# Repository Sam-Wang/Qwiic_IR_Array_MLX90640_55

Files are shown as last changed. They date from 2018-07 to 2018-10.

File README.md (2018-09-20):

Qwiic IR Array (MLX90640-55x35 FOV)
==================

Qwiic IR Array

[*Qwiic IR Array (SEN-14844)*](https://www.sparkfun.com/products/14844)

The MLX90640 contains a 32x24 array of thermopile sensors creating, in essence, a low resolution thermal imaging camera.

Repository Contents
-------------------
* **/Documentation** - Datasheets. 
* **/Firmware** - Examples to use the MLX90640 with a microcontroller.
* **/Hardware** - All Eagle design files (.brd, .sch). 
* **/Production** - Various test jigs and large panel layouts used for production.

Documentation
--------------
* **[Library](https://github.com/sparkfun/SparkFun_MLX90640_Arduino_Example)** - Arduino library for the Qwiic IR Array.
* **[Hookup Guide](https://learn.sparkfun.com/tutorials/qwiic-ir-array-mlx90640-hookup-guide)** - Basic hookup guide for the Qwiic IR Array.

Product Versions
----------------
* [SEN-14844](https://www.sparkfun.com/products/14844)- SparkFun red version
* [SPX-14769](https://www.sparkfun.com/products/14769)- SparkX version

License Information
-------------------

The hardware is released under [Creative Commons ShareAlike 4.0 International](https://creativecommons.org/licenses/by-sa/4.0/).
The code is beerware; if you see me (or any other SparkFun employee) at the local, and you've found our code helpful, please buy us a round!

Distributed as-is; no warranty is given.

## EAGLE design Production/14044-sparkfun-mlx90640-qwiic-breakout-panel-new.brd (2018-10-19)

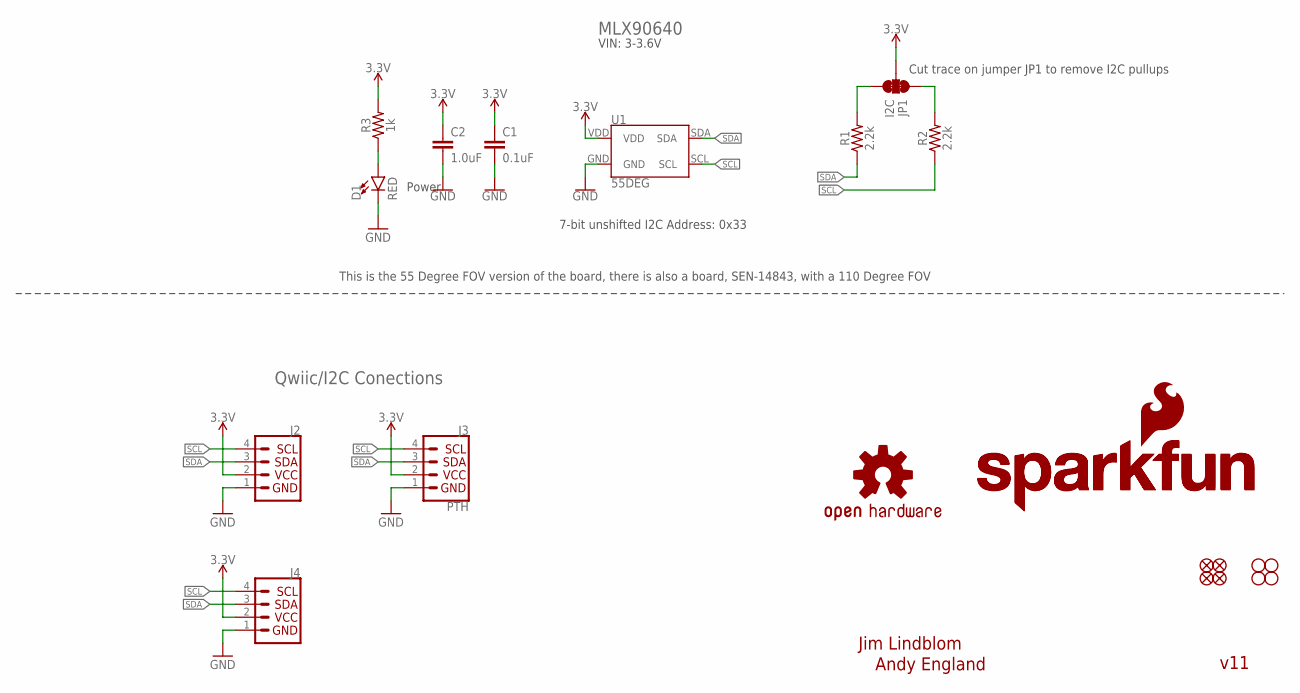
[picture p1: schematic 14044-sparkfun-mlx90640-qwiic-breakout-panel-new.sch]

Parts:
C1: 0.1uF; 0603
C2: 1.0uF; 0603
D1: RED; LED-0603
J2, J4: QWIIC_CONNECTORJS-1MM; 1X04_1MM_RA
J3: PTH; 1X04_NO_SILK
JP1: I2C; SMT-JUMPER_3_2-NC_TRACE_NO-SILK
JP2, JP5, JP6, JP7: FIDUCIALUFIDUCIAL; MICRO-FIDUCIAL
JP3, JP4, JP8, JP9: STAND-OFF
LOGO1: OSHW-LOGOMINI; OSHW-LOGO-MINI
LOGO2: SFE_LOGO_NAME_FLAME.1_INCH; SFE_LOGO_NAME_FLAME_.1
LOGO3: SFE_LOGO_NAME.1_INCH; SFE_LOGO_NAME_.1
R1, R2: 2.2k; 0603
R3: 1k; 0603
U1: 55DEG; MLX90540_MLX90640

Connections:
3.3V: C1.1, C2.1, J2.2, J3.2 (VCC), J4.2, JP1.2, R3.2, U1.VDD
GND: C1.2, C2.2, D1.C, J2.1, J3.1 (GND), J4.1, U1.GND
unnamed: JP1.3, R1.2
unnamed: JP1.1, R2.2
unnamed: D1.A, R3.1
SCL: J2.4, J3.4 (SCL), J4.4, R2.1, U1.SCL
SDA: J2.3, J3.3 (SDA), J4.3, R1.1, U1.SDA

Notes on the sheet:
Power
Jim Lindblom
7-bit unshifted I2C Address: 0x33
v11
Andy England
MLX90640
Qwiic/I2C Conections
VIN: 3-3.6V
This is the 55 Degree FOV version of the board, there is also a board, SEN-14843, with a 110 Degree FOV
Cut trace on jumper JP1 to remove I2C pullups

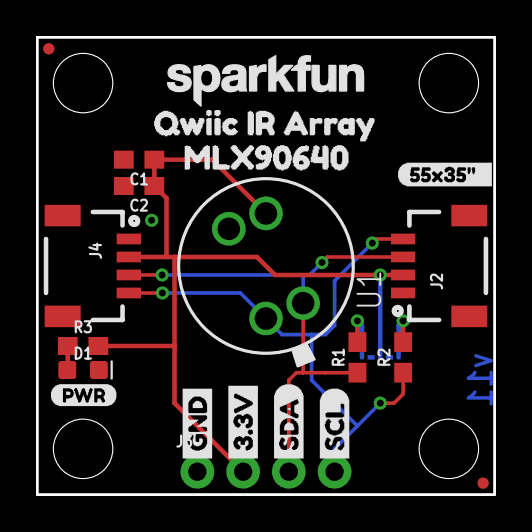
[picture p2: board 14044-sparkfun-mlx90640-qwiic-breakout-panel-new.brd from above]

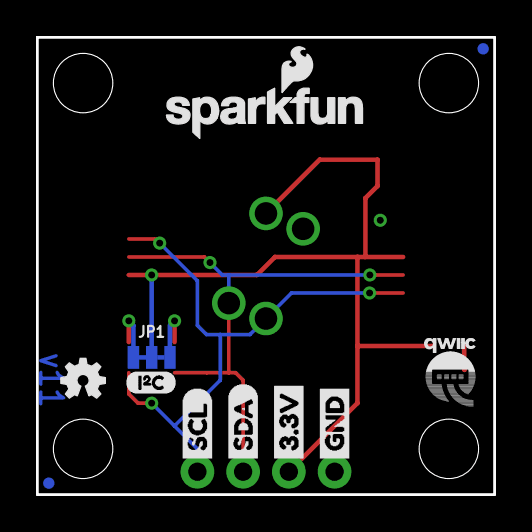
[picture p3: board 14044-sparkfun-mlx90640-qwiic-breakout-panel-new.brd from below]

Board: 2 copper layers, 25.4 x 25.4 mm, 36 parts (11 on the bottom side), 7 nets.

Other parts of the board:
U$1, U$7: SDA-[)
U$2: 55X35#__0
U$4, U$8: SCL-[)
U$5, U$9: 3.3V
U$6, U$10: GND-04
U$11: QWIIC-LOGO-SMALL
U$12: PWR-()-03
U$13: MLX906401
U$14: QWIIC_IR_ARRAY0
U$16: I_SUPER2_C-()-03

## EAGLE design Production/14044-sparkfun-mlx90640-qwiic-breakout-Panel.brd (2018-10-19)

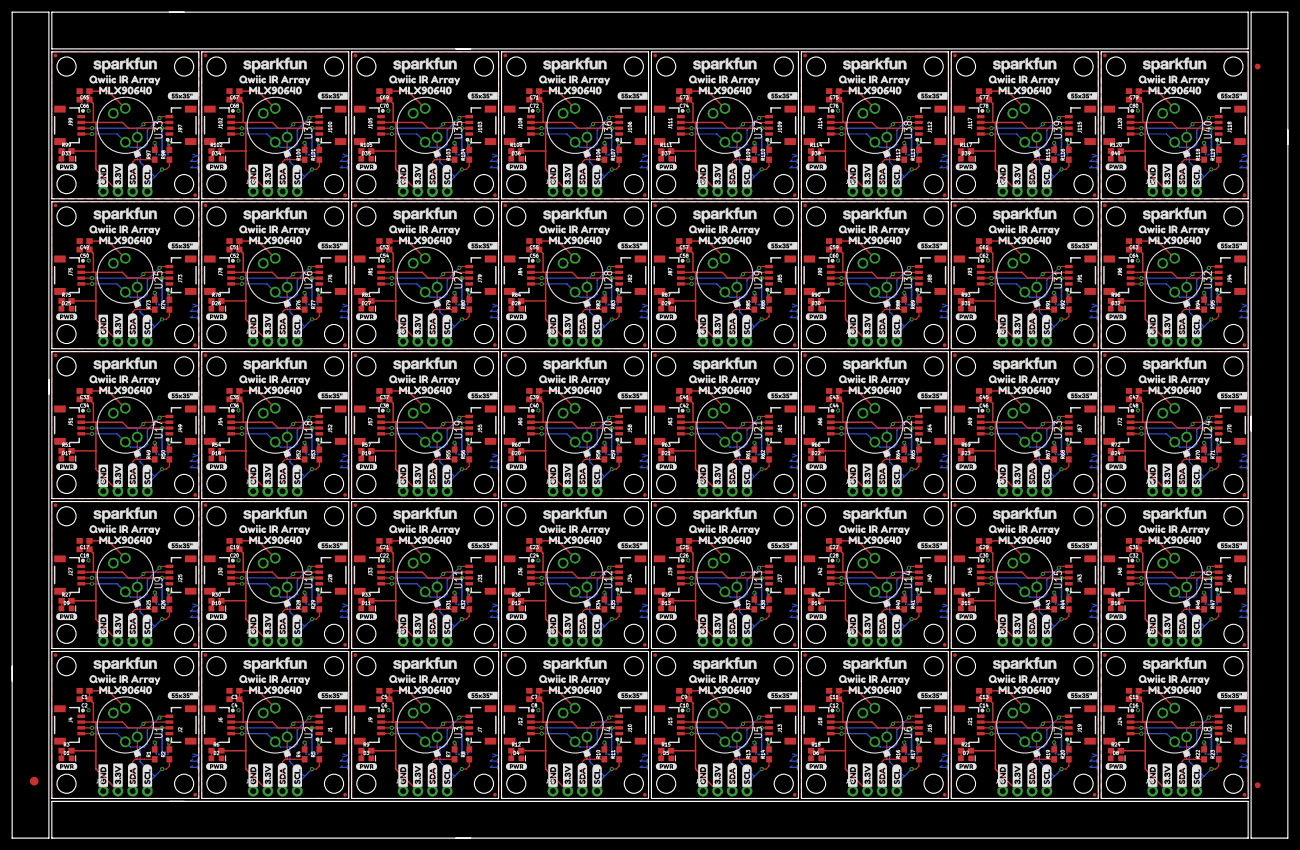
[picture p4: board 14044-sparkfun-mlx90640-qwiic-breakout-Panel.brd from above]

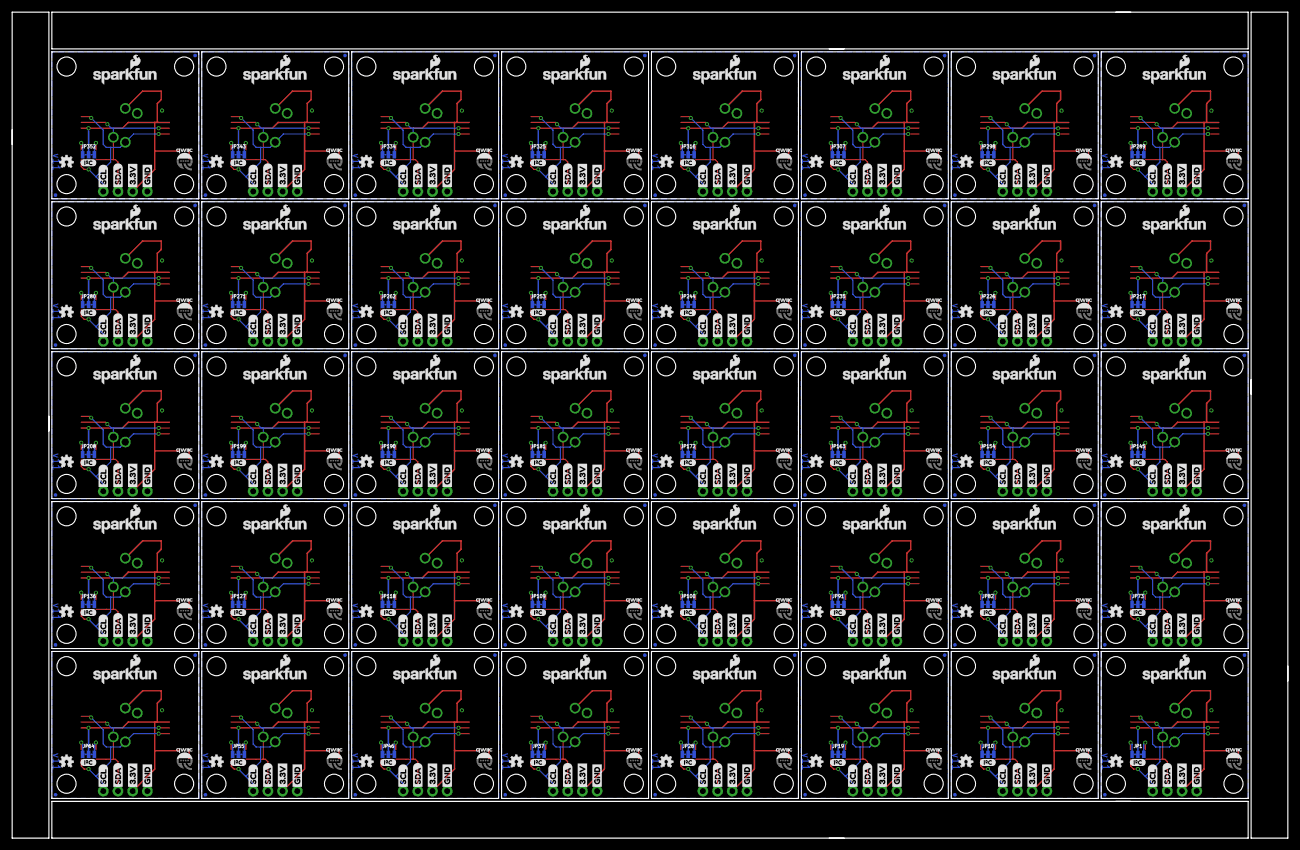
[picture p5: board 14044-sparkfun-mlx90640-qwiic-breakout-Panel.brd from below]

Board: 2 copper layers, 220.5 x 142.7 mm, 1443 parts (440 on the bottom side), 280 nets.

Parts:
C1, C3, C5, C7, C9, C11, C13, C15, C17, C19, C21, C23, C25, C27, C29, C31, C33, C35, C37, C39, C41, C43, C45, C47, C49, C51, C53, C55, C57, C59, C61, C63, C65, C67, C69, C71, C73, C75, C77, C79: 0.1uF; 0603
C2, C4, C6, C8, C10, C12, C14, C16, C18, C20, C22, C24, C26, C28, C30, C32, C34, C36, C38, C40, C42, C44, C46, C48, C50, C52, C54, C56, C58, C60, C62, C64, C66, C68, C70, C72, C74, C76, C78, C80: 1.0uF; 0603
D1, D2, D3, D4, D5, D6, D7, D8, D9, D10, D11, D12, D13, D14, D15, D16, D17, D18, D19, D20, D21, D22, D23, D24, D25, D26, D27, D28, D29, D30, D31, D32, D33, D34, D35, D36, D37, D38, D39, D40: RED; LED-0603
E$3: FIDUCIAL-1.5X3
E$7, E$8: FIDUCIAL-1X2
J1, J2, J4, J6, J7, J9, J10, J12, J13, J15, J16, J18, J19, J21, J22, J24, J25, J27, J28, J30, J31, J33, J34, J36, J37, J39, J40, J42, J43, J45, J46, J48, J49, J51, J52, J54, J55, J57, J58, J60, J61, J63, J64, J66, J67, J69, J70, J72, J73, J75, J76, J78, J79, J81, J82, J84, J85, J87, J88, J90, J91, J93, J94, J96, J97, J99, J100, J102, J103, J105, J106, J108, J109, J111, J112, J114, J115, J117, J118, J120: 1X04_1MM_RA
J3, J5, J8, J11, J14, J17, J20, J23, J26, J29, J32, J35, J38, J41, J44, J47, J50, J53, J56, J59, J62, J65, J68, J71, J74, J77, J80, J83, J86, J89, J92, J95, J98, J101, J104, J107, J110, J113, J116, J119: PTH; 1X04_NO_SILK
JP1, JP10, JP19, JP28, JP37, JP46, JP55, JP64, JP73, JP82, JP91, JP100, JP109, JP118, JP127, JP136, JP145, JP154, JP163, JP172, JP181, JP190, JP199, JP208, JP217, JP226, JP235, JP244, JP253, JP262, JP271, JP280, JP289, JP298, JP307, JP316, JP325, JP334, JP343, JP352: I2C; SMT-JUMPER_3_2-NC_TRACE_NO-SILK
JP2, JP5, JP6, JP7, JP13, JP14, JP15, JP16, JP22, JP23, JP24, JP25, JP31, JP32, JP33, JP34, JP40, JP41, JP42, JP43, JP49, JP50, JP51, JP52, JP58, JP59, JP60, JP61, JP67, JP68, JP69, JP70, JP76, JP77, JP78, JP79, JP85, JP86, JP87, JP88, JP94, JP95, JP96, JP97, JP103, JP104, JP105, JP106, JP112, JP113, JP114, JP115, JP121, JP122, JP123, JP124, JP130, JP131, JP132, JP133, JP139, JP140, JP141, JP142, JP148, JP149, JP150, JP151, JP157, JP158, JP159, JP160, JP166, JP167, JP168, JP169, JP175, JP176, JP177, JP178, JP184, JP185, JP186, JP187, JP193, JP194, JP195, JP196, JP202, JP203, JP204, JP205, JP211, JP212, JP213, JP214, JP220, JP221, JP222, JP223, JP229, JP230, JP231, JP232, JP238, JP239, JP240, JP241, JP247, JP248, JP249, JP250, JP256, JP257, JP258, JP259, JP265, JP266, JP267, JP268, JP274, JP275, JP276, JP277, JP283, JP284, JP285, JP286, JP292, JP293, JP294, JP295, JP301, JP302, JP303, JP304, JP310, JP311, JP312, JP313, JP319, JP320, JP321, JP322, JP328, JP329, JP330, JP331, JP337, JP338, JP339, JP340, JP346, JP347, JP348, JP349, JP355, JP356, JP357, JP358: FIDUCIALUFIDUCIAL; MICRO-FIDUCIAL
JP3, JP4, JP8, JP9, JP11, JP12, JP17, JP18, JP20, JP21, JP26, JP27, JP29, JP30, JP35, JP36, JP38, JP39, JP44, JP45, JP47, JP48, JP53, JP54, JP56, JP57, JP62, JP63, JP65, JP66, JP71, JP72, JP74, JP75, JP80, JP81, JP83, JP84, JP89, JP90, JP92, JP93, JP98, JP99, JP101, JP102, JP107, JP108, JP110, JP111, JP116, JP117, JP119, JP120, JP125, JP126, JP128, JP129, JP134, JP135, JP137, JP138, JP143, JP144, JP146, JP147, JP152, JP153, JP155, JP156, JP161, JP162, JP164, JP165, JP170, JP171, JP173, JP174, JP179, JP180, JP182, JP183, JP188, JP189, JP191, JP192, JP197, JP198, JP200, JP201, JP206, JP207, JP209, JP210, JP215, JP216, JP218, JP219, JP224, JP225, JP227, JP228, JP233, JP234, JP236, JP237, JP242, JP243, JP245, JP246, JP251, JP252, JP254, JP255, JP260, JP261, JP263, JP264, JP269, JP270, JP272, JP273, JP278, JP279, JP281, JP282, JP287, JP288, JP290, JP291, JP296, JP297, JP299, JP300, JP305, JP306, JP308, JP309, JP314, JP315, JP317, JP318, JP323, JP324, JP326, JP327, JP332, JP333, JP335, JP336, JP341, JP342, JP344, JP345, JP350, JP351, JP353, JP354, JP359, JP360: STAND-OFF
LOGO1, LOGO4, LOGO7, LOGO10, LOGO13, LOGO16, LOGO19, LOGO22, LOGO25, LOGO28, LOGO31, LOGO34, LOGO37, LOGO40, LOGO43, LOGO46, LOGO49, LOGO52, LOGO55, LOGO58, LOGO61, LOGO64, LOGO67, LOGO70, LOGO73, LOGO76, LOGO79, LOGO82, LOGO85, LOGO88, LOGO91, LOGO94, LOGO97, LOGO100, LOGO103, LOGO106, LOGO109, LOGO112, LOGO115, LOGO118: OSHW-LOGOMINI; OSHW-LOGO-MINI
LOGO2, LOGO5, LOGO8, LOGO11, LOGO14, LOGO17, LOGO20, LOGO23, LOGO26, LOGO29, LOGO32, LOGO35, LOGO38, LOGO41, LOGO44, LOGO47, LOGO50, LOGO53, LOGO56, LOGO59, LOGO62, LOGO65, LOGO68, LOGO71, LOGO74, LOGO77, LOGO80, LOGO83, LOGO86, LOGO89, LOGO92, LOGO95, LOGO98, LOGO101, LOGO104, LOGO107, LOGO110, LOGO113, LOGO116, LOGO119: SFE_LOGO_NAME_FLAME.1_INCH; SFE_LOGO_NAME_FLAME_.1
LOGO3, LOGO6, LOGO9, LOGO12, LOGO15, LOGO18, LOGO21, LOGO24, LOGO27, LOGO30, LOGO33, LOGO36, LOGO39, LOGO42, LOGO45, LOGO48, LOGO51, LOGO54, LOGO57, LOGO60, LOGO63, LOGO66, LOGO69, LOGO72, LOGO75, LOGO78, LOGO81, LOGO84, LOGO87, LOGO90, LOGO93, LOGO96, LOGO99, LOGO102, LOGO105, LOGO108, LOGO111, LOGO114, LOGO117, LOGO120: SFE_LOGO_NAME.1_INCH; SFE_LOGO_NAME_.1
R1, R2, R4, R5, R7, R8, R10, R11, R13, R14, R16, R17, R19, R20, R22, R23, R25, R26, R28, R29, R31, R32, R34, R35, R37, R38, R40, R41, R43, R44, R46, R47, R49, R50, R52, R53, R55, R56, R58, R59, R61, R62, R64, R65, R67, R68, R70, R71, R73, R74, R76, R77, R79, R80, R82, R83, R85, R86, R88, R89, R91, R92, R94, R95, R97, R98, R100, R101, R103, R104, R106, R107, R109, R110, R112, R113, R115, R116, R118, R119: 2.2k; 0603
R3, R6, R9, R12, R15, R18, R21, R24, R27, R30, R33, R36, R39, R42, R45, R48, R51, R54, R57, R60, R63, R66, R69, R72, R75, R78, R81, R84, R87, R90, R93, R96, R99, R102, R105, R108, R111, R114, R117, R120: 1k; 0603
U1, U2, U3, U4, U5, U6, U7, U8, U9, U10, U11, U12, U13, U14, U15, U16, U17, U18, U19, U20, U21, U22, U23, U24, U25, U26, U27, U28, U29, U30, U31, U32, U33, U34, U35, U36, U37, U38, U39, U40: 55DEG; MLX90540_MLX90640
U$1, U$3, U$7, U$19, U$29, U$33, U$43, U$47, U$57, U$61, U$71, U$75, U$85, U$89, U$99, U$103, U$113, U$117, U$127, U$131, U$141, U$145, U$155, U$159, U$169, U$173, U$183, U$187, U$197, U$201, U$211, U$215, U$225, U$229, U$239, U$243, U$253, U$257, U$267, U$271, U$281, U$285, U$295, U$299, U$309, U$313, U$323, U$327, U$337, U$341, U$351, U$355, U$365, U$369, U$379, U$383, U$393, U$397, U$407, U$411, U$421, U$425, U$435, U$439, U$449, U$453, U$463, U$467, U$477, U$481, U$491, U$495, U$505, U$509, U$519, U$523, U$533, U$537, U$547, U$551: SDA-[)
U$2, U$28, U$42, U$56, U$70, U$84, U$98, U$112, U$126, U$140, U$154, U$168, U$182, U$196, U$210, U$224, U$238, U$252, U$266, U$280, U$294, U$308, U$322, U$336, U$350, U$364, U$378, U$392, U$406, U$420, U$434, U$448, U$462, U$476, U$490, U$504, U$518, U$532, U$546, U$560: 55X35#__0
U$4, U$8, U$15, U$20, U$30, U$34, U$44, U$48, U$58, U$62, U$72, U$76, U$86, U$90, U$100, U$104, U$114, U$118, U$128, U$132, U$142, U$146, U$156, U$160, U$170, U$174, U$184, U$188, U$198, U$202, U$212, U$216, U$226, U$230, U$240, U$244, U$254, U$258, U$268, U$272, U$282, U$286, U$296, U$300, U$310, U$314, U$324, U$328, U$338, U$342, U$352, U$356, U$366, U$370, U$380, U$384, U$394, U$398, U$408, U$412, U$422, U$426, U$436, U$440, U$450, U$454, U$464, U$468, U$478, U$482, U$492, U$496, U$506, U$510, U$520, U$524, U$534, U$538, U$548, U$552: SCL-[)
U$5, U$9, U$17, U$21, U$31, U$35, U$45, U$49, U$59, U$63, U$73, U$77, U$87, U$91, U$101, U$105, U$115, U$119, U$129, U$133, U$143, U$147, U$157, U$161, U$171, U$175, U$185, U$189, U$199, U$203, U$213, U$217, U$227, U$231, U$241, U$245, U$255, U$259, U$269, U$273, U$283, U$287, U$297, U$301, U$311, U$315, U$325, U$329, U$339, U$343, U$353, U$357, U$367, U$371, U$381, U$385, U$395, U$399, U$409, U$413, U$423, U$427, U$437, U$441, U$451, U$455, U$465, U$469, U$479, U$483, U$493, U$497, U$507, U$511, U$521, U$525, U$535, U$539, U$549, U$553: 3.3V
U$6, U$10, U$18, U$22, U$32, U$36, U$46, U$50, U$60, U$64, U$74, U$78, U$88, U$92, U$102, U$106, U$116, U$120, U$130, U$134, U$144, U$148, U$158, U$162, U$172, U$176, U$186, U$190, U$200, U$204, U$214, U$218, U$228, U$232, U$242, U$246, U$256, U$260, U$270, U$274, U$284, U$288, U$298, U$302, U$312, U$316, U$326, U$330, U$340, U$344, U$354, U$358, U$368, U$372, U$382, U$386, U$396, U$400, U$410, U$414, U$424, U$428, U$438, U$442, U$452, U$456, U$466, U$470, U$480, U$484, U$494, U$498, U$508, U$512, U$522, U$526, U$536, U$540, U$550, U$554: GND-04
U$11, U$23, U$37, U$51, U$65, U$79, U$93, U$107, U$121, U$135, U$149, U$163, U$177, U$191, U$205, U$219, U$233, U$247, U$261, U$275, U$289, U$303, U$317, U$331, U$345, U$359, U$373, U$387, U$401, U$415, U$429, U$443, U$457, U$471, U$485, U$499, U$513, U$527, U$541, U$555: QWIIC-LOGO-SMALL
U$12, U$24, U$38, U$52, U$66, U$80, U$94, U$108, U$122, U$136, U$150, U$164, U$178, U$192, U$206, U$220, U$234, U$248, U$262, U$276, U$290, U$304, U$318, U$332, U$346, U$360, U$374, U$388, U$402, U$416, U$430, U$444, U$458, U$472, U$486, U$500, U$514, U$528, U$542, U$556: PWR-()-03
U$13, U$25, U$39, U$53, U$67, U$81, U$95, U$109, U$123, U$137, U$151, U$165, U$179, U$193, U$207, U$221, U$235, U$249, U$263, U$277, U$291, U$305, U$319, U$333, U$347, U$361, U$375, U$389, U$403, U$417, U$431, U$445, U$459, U$473, U$487, U$501, U$515, U$529, U$543, U$557: MLX906401
U$14, U$26, U$40, U$54, U$68, U$82, U$96, U$110, U$124, U$138, U$152, U$166, U$180, U$194, U$208, U$222, U$236, U$250, U$264, U$278, U$292, U$306, U$320, U$334, U$348, U$362, U$376, U$390, U$404, U$418, U$432, U$446, U$460, U$474, U$488, U$502, U$516, U$530, U$544, U$558: QWIIC_IR_ARRAY0
U$16, U$27, U$41, U$55, U$69, U$83, U$97, U$111, U$125, U$139, U$153, U$167, U$181, U$195, U$209, U$223, U$237, U$251, U$265, U$279, U$293, U$307, U$321, U$335, U$349, U$363, U$377, U$391, U$405, U$419, U$433, U$447, U$461, U$475, U$489, U$503, U$517, U$531, U$545, U$559: I_SUPER2_C-()-03

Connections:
3.3V: C1.1, C2.1, J2.2, J3.2, J4.2, JP1.2, R3.2, U1.VDD
3.3V1: C3.1, C4.1, J1.2, J5.2, J6.2, JP10.2, R6.2, U2.VDD
3.3V2: C5.1, C6.1, J7.2, J8.2, J9.2, JP19.2, R9.2, U3.VDD
3.3V3: C7.1, C8.1, J10.2, J11.2, J12.2, JP28.2, R12.2, U4.VDD
3.3V4: C9.1, C10.1, J13.2, J14.2, J15.2, JP37.2, R15.2, U5.VDD
3.3V5: C11.1, C12.1, J16.2, J17.2, J18.2, JP46.2, R18.2, U6.VDD
3.3V6: C13.1, C14.1, J19.2, J20.2, J21.2, JP55.2, R21.2, U7.VDD
3.3V7: C15.1, C16.1, J22.2, J23.2, J24.2, JP64.2, R24.2, U8.VDD
3.3V8: C17.1, C18.1, J25.2, J26.2, J27.2, JP73.2, R27.2, U9.VDD
3.3V9: C19.1, C20.1, J28.2, J29.2, J30.2, JP82.2, R30.2, U10.VDD
3.3V10: C21.1, C22.1, J31.2, J32.2, J33.2, JP91.2, R33.2, U11.VDD
3.3V11: C23.1, C24.1, J34.2, J35.2, J36.2, JP100.2, R36.2, U12.VDD
3.3V12: C25.1, C26.1, J37.2, J38.2, J39.2, JP109.2, R39.2, U13.VDD
3.3V13: C27.1, C28.1, J40.2, J41.2, J42.2, JP118.2, R42.2, U14.VDD
3.3V14: C29.1, C30.1, J43.2, J44.2, J45.2, JP127.2, R45.2, U15.VDD
3.3V15: C31.1, C32.1, J46.2, J47.2, J48.2, JP136.2, R48.2, U16.VDD
3.3V16: C33.1, C34.1, J49.2, J50.2, J51.2, JP145.2, R51.2, U17.VDD
3.3V17: C35.1, C36.1, J52.2, J53.2, J54.2, JP154.2, R54.2, U18.VDD
3.3V18: C37.1, C38.1, J55.2, J56.2, J57.2, JP163.2, R57.2, U19.VDD
3.3V19: C39.1, C40.1, J58.2, J59.2, J60.2, JP172.2, R60.2, U20.VDD
3.3V20: C41.1, C42.1, J61.2, J62.2, J63.2, JP181.2, R63.2, U21.VDD
3.3V21: C43.1, C44.1, J64.2, J65.2, J66.2, JP190.2, R66.2, U22.VDD
3.3V22: C45.1, C46.1, J67.2, J68.2, J69.2, JP199.2, R69.2, U23.VDD
3.3V23: C47.1, C48.1, J70.2, J71.2, J72.2, JP208.2, R72.2, U24.VDD
3.3V24: C49.1, C50.1, J73.2, J74.2, J75.2, JP217.2, R75.2, U25.VDD
3.3V25: C51.1, C52.1, J76.2, J77.2, J78.2, JP226.2, R78.2, U26.VDD
3.3V26: C53.1, C54.1, J79.2, J80.2, J81.2, JP235.2, R81.2, U27.VDD
3.3V27: C55.1, C56.1, J82.2, J83.2, J84.2, JP244.2, R84.2, U28.VDD
3.3V28: C57.1, C58.1, J85.2, J86.2, J87.2, JP253.2, R87.2, U29.VDD
3.3V29: C59.1, C60.1, J88.2, J89.2, J90.2, JP262.2, R90.2, U30.VDD
3.3V30: C61.1, C62.1, J91.2, J92.2, J93.2, JP271.2, R93.2, U31.VDD
3.3V31: C63.1, C64.1, J94.2, J95.2, J96.2, JP280.2, R96.2, U32.VDD
3.3V32: C65.1, C66.1, J97.2, J98.2, J99.2, JP289.2, R99.2, U33.VDD
3.3V33: C67.1, C68.1, J100.2, J101.2, J102.2, JP298.2, R102.2, U34.VDD
3.3V34: C69.1, C70.1, J103.2, J104.2, J105.2, JP307.2, R105.2, U35.VDD
3.3V35: C71.1, C72.1, J106.2, J107.2, J108.2, JP316.2, R108.2, U36.VDD
3.3V36: C73.1, C74.1, J109.2, J110.2, J111.2, JP325.2, R111.2, U37.VDD
3.3V37: C75.1, C76.1, J112.2, J113.2, J114.2, JP334.2, R114.2, U38.VDD
3.3V38: C77.1, C78.1, J115.2, J116.2, J117.2, JP343.2, R117.2, U39.VDD
3.3V39: C79.1, C80.1, J118.2, J119.2, J120.2, JP352.2, R120.2, U40.VDD
GND: C1.2, C2.2, D1.C, J2.1, J3.1, J4.1, U1.GND
GND1: C3.2, C4.2, D2.C, J1.1, J5.1, J6.1, U2.GND
GND2: C5.2, C6.2, D3.C, J7.1, J8.1, J9.1, U3.GND
GND3: C7.2, C8.2, D4.C, J10.1, J11.1, J12.1, U4.GND
GND4: C9.2, C10.2, D5.C, J13.1, J14.1, J15.1, U5.GND
GND5: C11.2, C12.2, D6.C, J16.1, J17.1, J18.1, U6.GND
GND6: C13.2, C14.2, D7.C, J19.1, J20.1, J21.1, U7.GND
GND7: C15.2, C16.2, D8.C, J22.1, J23.1, J24.1, U8.GND
GND8: C17.2, C18.2, D9.C, J25.1, J26.1, J27.1, U9.GND
GND9: C19.2, C20.2, D10.C, J28.1, J29.1, J30.1, U10.GND
GND10: C21.2, C22.2, D11.C, J31.1, J32.1, J33.1, U11.GND
GND11: C23.2, C24.2, D12.C, J34.1, J35.1, J36.1, U12.GND
GND12: C25.2, C26.2, D13.C, J37.1, J38.1, J39.1, U13.GND
GND13: C27.2, C28.2, D14.C, J40.1, J41.1, J42.1, U14.GND
GND14: C29.2, C30.2, D15.C, J43.1, J44.1, J45.1, U15.GND
GND15: C31.2, C32.2, D16.C, J46.1, J47.1, J48.1, U16.GND
GND16: C33.2, C34.2, D17.C, J49.1, J50.1, J51.1, U17.GND
GND17: C35.2, C36.2, D18.C, J52.1, J53.1, J54.1, U18.GND
GND18: C37.2, C38.2, D19.C, J55.1, J56.1, J57.1, U19.GND
GND19: C39.2, C40.2, D20.C, J58.1, J59.1, J60.1, U20.GND
GND20: C41.2, C42.2, D21.C, J61.1, J62.1, J63.1, U21.GND
GND21: C43.2, C44.2, D22.C, J64.1, J65.1, J66.1, U22.GND
GND22: C45.2, C46.2, D23.C, J67.1, J68.1, J69.1, U23.GND
GND23: C47.2, C48.2, D24.C, J70.1, J71.1, J72.1, U24.GND
GND24: C49.2, C50.2, D25.C, J73.1, J74.1, J75.1, U25.GND
GND25: C51.2, C52.2, D26.C, J76.1, J77.1, J78.1, U26.GND
GND26: C53.2, C54.2, D27.C, J79.1, J80.1, J81.1, U27.GND
GND27: C55.2, C56.2, D28.C, J82.1, J83.1, J84.1, U28.GND
GND28: C57.2, C58.2, D29.C, J85.1, J86.1, J87.1, U29.GND
GND29: C59.2, C60.2, D30.C, J88.1, J89.1, J90.1, U30.GND
GND30: C61.2, C62.2, D31.C, J91.1, J92.1, J93.1, U31.GND
GND31: C63.2, C64.2, D32.C, J94.1, J95.1, J96.1, U32.GND
GND32: C65.2, C66.2, D33.C, J97.1, J98.1, J99.1, U33.GND
GND33: C67.2, C68.2, D34.C, J100.1, J101.1, J102.1, U34.GND
GND34: C69.2, C70.2, D35.C, J103.1, J104.1, J105.1, U35.GND
GND35: C71.2, C72.2, D36.C, J106.1, J107.1, J108.1, U36.GND
GND36: C73.2, C74.2, D37.C, J109.1, J110.1, J111.1, U37.GND
GND37: C75.2, C76.2, D38.C, J112.1, J113.1, J114.1, U38.GND
GND38: C77.2, C78.2, D39.C, J115.1, J116.1, J117.1, U39.GND
GND39: C79.2, C80.2, D40.C, J118.1, J119.1, J120.1, U40.GND
unnamed: JP1.3, R1.2
unnamed: JP1.1, R2.2
unnamed: D1.A, R3.1
unnamed: JP10.3, R4.2
unnamed: JP10.1, R5.2
unnamed: D2.A, R6.1
unnamed: JP19.3, R7.2
unnamed: JP19.1, R8.2
unnamed: D3.A, R9.1
unnamed: JP28.3, R10.2
unnamed: JP28.1, R11.2
unnamed: D4.A, R12.1
unnamed: JP37.3, R13.2
unnamed: JP37.1, R14.2
unnamed: D5.A, R15.1
unnamed: JP46.3, R16.2
unnamed: JP46.1, R17.2
unnamed: D6.A, R18.1
unnamed: JP55.3, R19.2
unnamed: JP55.1, R20.2
unnamed: D7.A, R21.1
unnamed: JP64.3, R22.2
unnamed: JP64.1, R23.2
unnamed: D8.A, R24.1
unnamed: JP73.3, R25.2
unnamed: JP73.1, R26.2
unnamed: D9.A, R27.1
unnamed: JP82.3, R28.2
unnamed: JP82.1, R29.2
unnamed: D10.A, R30.1
unnamed: JP91.3, R31.2
unnamed: JP91.1, R32.2
unnamed: D11.A, R33.1
unnamed: JP100.3, R34.2
unnamed: JP100.1, R35.2
unnamed: D12.A, R36.1
unnamed: JP109.3, R37.2
unnamed: JP109.1, R38.2
unnamed: D13.A, R39.1
unnamed: JP118.3, R40.2
unnamed: JP118.1, R41.2
unnamed: D14.A, R42.1
unnamed: JP127.3, R43.2
unnamed: JP127.1, R44.2
unnamed: D15.A, R45.1
unnamed: JP136.3, R46.2
unnamed: JP136.1, R47.2
unnamed: D16.A, R48.1
unnamed: JP145.3, R49.2
unnamed: JP145.1, R50.2
unnamed: D17.A, R51.1
unnamed: JP154.3, R52.2
unnamed: JP154.1, R53.2
unnamed: D18.A, R54.1
unnamed: JP163.3, R55.2
unnamed: JP163.1, R56.2
unnamed: D19.A, R57.1
unnamed: JP172.3, R58.2
unnamed: JP172.1, R59.2
unnamed: D20.A, R60.1
unnamed: JP181.3, R61.2
unnamed: JP181.1, R62.2
unnamed: D21.A, R63.1
unnamed: JP190.3, R64.2
unnamed: JP190.1, R65.2
unnamed: D22.A, R66.1
unnamed: JP199.3, R67.2
unnamed: JP199.1, R68.2
unnamed: D23.A, R69.1
unnamed: JP208.3, R70.2
unnamed: JP208.1, R71.2
unnamed: D24.A, R72.1
unnamed: JP217.3, R73.2
unnamed: JP217.1, R74.2
unnamed: D25.A, R75.1
unnamed: JP226.3, R76.2
unnamed: JP226.1, R77.2
unnamed: D26.A, R78.1
unnamed: JP235.3, R79.2
unnamed: JP235.1, R80.2
unnamed: D27.A, R81.1
unnamed: JP244.3, R82.2
unnamed: JP244.1, R83.2
unnamed: D28.A, R84.1
unnamed: JP253.3, R85.2
unnamed: JP253.1, R86.2
unnamed: D29.A, R87.1
unnamed: JP262.3, R88.2
unnamed: JP262.1, R89.2
unnamed: D30.A, R90.1
unnamed: JP271.3, R91.2
unnamed: JP271.1, R92.2
unnamed: D31.A, R93.1
unnamed: JP280.3, R94.2
unnamed: JP280.1, R95.2
unnamed: D32.A, R96.1
unnamed: JP289.3, R97.2
unnamed: JP289.1, R98.2
unnamed: D33.A, R99.1
unnamed: JP298.3, R100.2
unnamed: JP298.1, R101.2
unnamed: D34.A, R102.1
unnamed: JP307.3, R103.2
unnamed: JP307.1, R104.2
unnamed: D35.A, R105.1
unnamed: JP316.3, R106.2
unnamed: JP316.1, R107.2
unnamed: D36.A, R108.1
unnamed: JP325.3, R109.2
unnamed: JP325.1, R110.2
unnamed: D37.A, R111.1
unnamed: JP334.3, R112.2
unnamed: JP334.1, R113.2
unnamed: D38.A, R114.1
unnamed: JP343.3, R115.2
unnamed: JP343.1, R116.2
unnamed: D39.A, R117.1
unnamed: JP352.3, R118.2
unnamed: JP352.1, R119.2
unnamed: D40.A, R120.1
SCL: J2.4, J3.4, J4.4, R2.1, U1.SCL
SCL1: J1.4, J5.4, J6.4, R5.1, U2.SCL
SCL2: J7.4, J8.4, J9.4, R8.1, U3.SCL
SCL3: J10.4, J11.4, J12.4, R11.1, U4.SCL
SCL4: J13.4, J14.4, J15.4, R14.1, U5.SCL
SCL5: J16.4, J17.4, J18.4, R17.1, U6.SCL
SCL6: J19.4, J20.4, J21.4, R20.1, U7.SCL
SCL7: J22.4, J23.4, J24.4, R23.1, U8.SCL
SCL8: J25.4, J26.4, J27.4, R26.1, U9.SCL
SCL9: J28.4, J29.4, J30.4, R29.1, U10.SCL
SCL10: J31.4, J32.4, J33.4, R32.1, U11.SCL
SCL11: J34.4, J35.4, J36.4, R35.1, U12.SCL
SCL12: J37.4, J38.4, J39.4, R38.1, U13.SCL
SCL13: J40.4, J41.4, J42.4, R41.1, U14.SCL
SCL14: J43.4, J44.4, J45.4, R44.1, U15.SCL
SCL15: J46.4, J47.4, J48.4, R47.1, U16.SCL
SCL16: J49.4, J50.4, J51.4, R50.1, U17.SCL
SCL17: J52.4, J53.4, J54.4, R53.1, U18.SCL
SCL18: J55.4, J56.4, J57.4, R56.1, U19.SCL
SCL19: J58.4, J59.4, J60.4, R59.1, U20.SCL
SCL20: J61.4, J62.4, J63.4, R62.1, U21.SCL
SCL21: J64.4, J65.4, J66.4, R65.1, U22.SCL
SCL22: J67.4, J68.4, J69.4, R68.1, U23.SCL
SCL23: J70.4, J71.4, J72.4, R71.1, U24.SCL
SCL24: J73.4, J74.4, J75.4, R74.1, U25.SCL
SCL25: J76.4, J77.4, J78.4, R77.1, U26.SCL
SCL26: J79.4, J80.4, J81.4, R80.1, U27.SCL
SCL27: J82.4, J83.4, J84.4, R83.1, U28.SCL
SCL28: J85.4, J86.4, J87.4, R86.1, U29.SCL
SCL29: J88.4, J89.4, J90.4, R89.1, U30.SCL
SCL30: J91.4, J92.4, J93.4, R92.1, U31.SCL
SCL31: J94.4, J95.4, J96.4, R95.1, U32.SCL
SCL32: J97.4, J98.4, J99.4, R98.1, U33.SCL
SCL33: J100.4, J101.4, J102.4, R101.1, U34.SCL
SCL34: J103.4, J104.4, J105.4, R104.1, U35.SCL
SCL35: J106.4, J107.4, J108.4, R107.1, U36.SCL
SCL36: J109.4, J110.4, J111.4, R110.1, U37.SCL
SCL37: J112.4, J113.4, J114.4, R113.1, U38.SCL
SCL38: J115.4, J116.4, J117.4, R116.1, U39.SCL
SCL39: J118.4, J119.4, J120.4, R119.1, U40.SCL
SDA: J2.3, J3.3, J4.3, R1.1, U1.SDA
SDA1: J1.3, J5.3, J6.3, R4.1, U2.SDA
SDA2: J7.3, J8.3, J9.3, R7.1, U3.SDA
SDA3: J10.3, J11.3, J12.3, R10.1, U4.SDA
SDA4: J13.3, J14.3, J15.3, R13.1, U5.SDA
SDA5: J16.3, J17.3, J18.3, R16.1, U6.SDA
SDA6: J19.3, J20.3, J21.3, R19.1, U7.SDA
SDA7: J22.3, J23.3, J24.3, R22.1, U8.SDA
SDA8: J25.3, J26.3, J27.3, R25.1, U9.SDA
SDA9: J28.3, J29.3, J30.3, R28.1, U10.SDA
SDA10: J31.3, J32.3, J33.3, R31.1, U11.SDA
SDA11: J34.3, J35.3, J36.3, R34.1, U12.SDA
SDA12: J37.3, J38.3, J39.3, R37.1, U13.SDA
SDA13: J40.3, J41.3, J42.3, R40.1, U14.SDA
SDA14: J43.3, J44.3, J45.3, R43.1, U15.SDA
SDA15: J46.3, J47.3, J48.3, R46.1, U16.SDA
SDA16: J49.3, J50.3, J51.3, R49.1, U17.SDA
SDA17: J52.3, J53.3, J54.3, R52.1, U18.SDA
SDA18: J55.3, J56.3, J57.3, R55.1, U19.SDA
SDA19: J58.3, J59.3, J60.3, R58.1, U20.SDA
SDA20: J61.3, J62.3, J63.3, R61.1, U21.SDA
SDA21: J64.3, J65.3, J66.3, R64.1, U22.SDA
SDA22: J67.3, J68.3, J69.3, R67.1, U23.SDA
SDA23: J70.3, J71.3, J72.3, R70.1, U24.SDA
SDA24: J73.3, J74.3, J75.3, R73.1, U25.SDA
SDA25: J76.3, J77.3, J78.3, R76.1, U26.SDA
SDA26: J79.3, J80.3, J81.3, R79.1, U27.SDA
SDA27: J82.3, J83.3, J84.3, R82.1, U28.SDA
SDA28: J85.3, J86.3, J87.3, R85.1, U29.SDA
SDA29: J88.3, J89.3, J90.3, R88.1, U30.SDA
SDA30: J91.3, J92.3, J93.3, R91.1, U31.SDA
SDA31: J94.3, J95.3, J96.3, R94.1, U32.SDA
SDA32: J97.3, J98.3, J99.3, R97.1, U33.SDA
SDA33: J100.3, J101.3, J102.3, R100.1, U34.SDA
SDA34: J103.3, J104.3, J105.3, R103.1, U35.SDA
SDA35: J106.3, J107.3, J108.3, R106.1, U36.SDA
SDA36: J109.3, J110.3, J111.3, R109.1, U37.SDA
SDA37: J112.3, J113.3, J114.3, R112.1, U38.SDA
SDA38: J115.3, J116.3, J117.3, R115.1, U39.SDA
SDA39: J118.3, J119.3, J120.3, R118.1, U40.SDA

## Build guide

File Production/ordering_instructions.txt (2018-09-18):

panel size, 221x143mm
PCB thickness, 1.6mm
number of layers, 2
soldermask color, Red
silkscreen color, White
oz copper, 1oz
finish, HASL lead free
stencils, none
pcs per panel, 40

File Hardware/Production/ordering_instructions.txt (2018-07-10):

panel size, 91x91mm
PCB thickness, 1.6mm
number of layers, 2
soldermask color, Black
silkscreen color, White
oz copper, 1oz
finish, HASL lead free
stencils, top+bottom
pcs per panel, 9

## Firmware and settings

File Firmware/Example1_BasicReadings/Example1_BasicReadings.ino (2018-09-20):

/*
  Read the temperature pixels from the MLX90640 IR array
  By: Nathan Seidle
  SparkFun Electronics
  Date: May 22nd, 2018
  License: MIT. See license file for more information but you can
  basically do whatever you want with this code.

  Feel like supporting open source hardware?
  Buy a board from SparkFun! https://www.sparkfun.com/products/14769

  This example initializes the MLX90640 and outputs the 768 temperature values
  from the 768 pixels.

  This example will work with a Teensy 3.1 and above. The MLX90640 requires some
  hefty calculations and larger arrays. You will need a microcontroller with 20,000
  bytes or more of RAM.

  This relies on the driver written by Melexis and can be found at:
  https://github.com/melexis/mlx90640-library

  Hardware Connections:
  Connect the SparkFun Qwiic Breadboard Jumper (https://www.sparkfun.com/products/14425)
  to the Qwiic board
  Connect the male pins to the Teensy. The pinouts can be found here: https://www.pjrc.com/teensy/pinout.html
  Open the serial monitor at 9600 baud to see the output
*/

#include <Wire.h>

#include "MLX90640_API.h"
#include "MLX90640_I2C_Driver.h"

const byte MLX90640_address = 0x33; //Default 7-bit unshifted address of the MLX90640

#define TA_SHIFT 8 //Default shift for MLX90640 in open air

static float mlx90640To[768];
paramsMLX90640 mlx90640;

void setup()
{
  Wire.begin();
  Wire.setClock(400000); //Increase I2C clock speed to 400kHz

  Serial.begin(9600);
  while (!Serial); //Wait for user to open terminal
  Serial.println("MLX90640 IR Array Example");

  if (isConnected() == false)
  {
    Serial.println("MLX90640 not detected at default I2C address. Please check wiring. Freezing.");
    while (1);
  }
  Serial.println("MLX90640 online!");

  //Get device parameters - We only have to do this once
  int status;
  uint16_t eeMLX90640[832];
  status = MLX90640_DumpEE(MLX90640_address, eeMLX90640);
  if (status != 0)
    Serial.println("Failed to load system parameters");

  status = MLX90640_ExtractParameters(eeMLX90640, &mlx90640);
  if (status != 0)
    Serial.println("Parameter extraction failed");

  //Once params are extracted, we can release eeMLX90640 array
}

void loop()
{
  for (byte x = 0 ; x < 2 ; x++) //Read both subpages
  {
    uint16_t mlx90640Frame[834];
    int status = MLX90640_GetFrameData(MLX90640_address, mlx90640Frame);
    if (status < 0)
    {
      Serial.print("GetFrame Error: ");
      Serial.println(status);
    }

    float vdd = MLX90640_GetVdd(mlx90640Frame, &mlx90640);
    float Ta = MLX90640_GetTa(mlx90640Frame, &mlx90640);

    float tr = Ta - TA_SHIFT; //Reflected temperature based on the sensor ambient temperature
    float emissivity = 0.95;

    MLX90640_CalculateTo(mlx90640Frame, &mlx90640, emissivity, tr, mlx90640To);
  }

  for (int x = 0 ; x < 10 ; x++)
  {
    Serial.print("Pixel ");
    Serial.print(x);
    Serial.print(": ");
    Serial.print(mlx90640To[x], 2);
    Serial.print("C");
    Serial.println();
  }

  delay(1000);
}

//Returns true if the MLX90640 is detected on the I2C bus
boolean isConnected()
{
  Wire.beginTransmission((uint8_t)MLX90640_address);
  if (Wire.endTransmission() != 0)
    return (false); //Sensor did not ACK
  return (true);
}

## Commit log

2018-07-10 updating to reds
    [sparkfun-mlx90640-qwiic-breakout-Panel.GBL, sparkfun-mlx90640-qwiic-breakout-Panel.GBO, sparkfun-mlx90640-qwiic-breakout-Panel.GBS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]
2018-07-17 post design review changes
    [sparkfun-mlx90640-qwiic-breakout.brd, sparkfun-mlx90640-qwiic-breakout.sch]
2018-07-30 fixing issues
    [sparkfun-mlx90640-qwiic-breakout.brd, sparkfun-mlx90640-qwiic-breakout.sch]
2018-08-03 panel v10 created
    [14044-sparkfun-mlx90640-qwiic-breakout-Panel.brd]
2018-09-18 updating to kit package
    [sparkfun-mlx90640-qwiic-breakout.brd, sparkfun-mlx90640-qwiic-breakout.sch]

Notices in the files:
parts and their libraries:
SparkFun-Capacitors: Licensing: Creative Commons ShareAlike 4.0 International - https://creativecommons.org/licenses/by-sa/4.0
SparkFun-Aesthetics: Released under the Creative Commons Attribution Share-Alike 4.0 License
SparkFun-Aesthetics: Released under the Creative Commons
